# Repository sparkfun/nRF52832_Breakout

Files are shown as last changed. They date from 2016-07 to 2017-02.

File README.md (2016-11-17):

SparkFun nRF52832 Breakout
========================================

SparkFun nRF52832 Breakout (https://www.sparkfun.com/products/13990)

[*SparkFun nRF52832 Breakout (WRL-13990)*](https://www.sparkfun.com/products/13990)

The nRF52832 is [Nordic Semiconductor's](https://www.nordicsemi.com/eng/Products/Bluetooth-low-energy/nRF52832) latest multiprotocol radio system-on-chip (SoC). It's half microcontroller, with a list of features including 32 configurable I/O pins, SPI, I<sup>2</sup>C, UART, PWM, ADC's, 512kB flash, and 64kB RAM. And, it's half 2.4GHz multiprotocol radio, supporting **Bluetooth low energy** (BLE), **ANT**, and Nordic's proprietary 2.4GHz ultra low-power wireless communication -- it even features on-chip NFC tag support.

SparkFun's [nRF52832 Breakout](https://www.sparkfun.com/products/13990) provides easy access to all of the chip's features. It breaks out all of the nRF52's I/O pins, provides a 32.768kHz RTC crystal, a user-programmable button and LED, and a trace antenna to send and receive those 2.4GHz transmissions. Plus, to make the chip as easy-to-flash as possible, the breakout comes pre-programmed with a **serial bootloader**.

Repository Contents
-------------------

* **/Documentation** - Data sheets, additional product information
* **/Firmware** - Serial bootloader source and hex files
* **/Hardware** - Eagle design files (.brd, .sch)
* **/Production** - Production panel files (.brd)

Documentation
--------------
* **[Arduino Hardware Definitions](https://github.com/sparkfun/Arduino_Boards/)** - Arduino cores and tools for the nRF52.
* **[Hookup Guide](https://learn.sparkfun.com/tutorials/nrf52832-breakout-board-hookup-guide)** - Basic hookup guide for the nRF52832 Breakout.
* **[SparkFun Fritzing repo](https://github.com/sparkfun/Fritzing_Parts)** - Fritzing diagrams for SparkFun products.

Product Versions
----------------
* [SparkFun nRF52832 Breakout (WRL-13990)](https://www.sparkfun.com/products/13990)- Initial release of the nRF52832 Breakout

Version History
---------------

License Information
-------------------

This product is _**open source**_! 

Please review the LICENSE.md file for license information. 

If you have any questions or concerns on licensing, please contact techsupport@sparkfun.com.

Distributed as-is; no warranty is given.

- Your friends at SparkFun.

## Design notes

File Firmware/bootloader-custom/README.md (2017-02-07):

nRF52832 HCI/UART DFU Bootloader - From nRF5 SDK v11.0.0
======================================================

Device firmware update (DFU) bootloader which allows the nRF52832's firmware and/or SoftDevice to be updated serially.

[nrfutil v0.5.2](https://github.com/NordicSemiconductor/pc-nrfutil/releases/tag/v0.5.2) can be used to transfer a firmware image from computer to nRF52832.

To enter the bootloader, pin 6 -- attached to a button on the SparkFun nRF52832 Breakout -- must be held low on startup or reset. The LED on pin 7 will blink in a "timebomb" pattern to indicate the board is in the bootloader state.

For more information on the Nordic BLE & HCI/UART Bootloader/DFU, check out their [SDK Reference Page](http://infocenter.nordicsemi.com/topic/com.nordic.infocenter.sdk5.v11.0.0/examples_ble_dfu.html).

### Contents

* **/config** -- Platform-specific configurations.
* **/hex** -- Compiled hex files for the SoftDevice (S132) and bootloader.
* **main.c** -- Main source file for bootloader application

### Toolchain Requirements

To compile this bootloader, you'll need [armgcc](https://launchpad.net/gcc-arm-embedded) and Nordic's [nRF5_SDK_V11.0.0](https://developer.nordicsemi.com/nRF5_SDK/nRF5_SDK_v11.x.x/).

Documentation for the nRF5 SDK (v11.0.0) can be found at [http://infocenter.nordicsemi.com/index.jsp?topic=%2Fcom.nordic.infocenter.sdk5.v11.0.0%2Findex.html](http://infocenter.nordicsemi.com/index.jsp?topic=%2Fcom.nordic.infocenter.sdk5.v11.0.0%2Findex.html). Follow along with the instructions there to install and set up the SDK. Note that GCC is used instead of Keil or IAR.

### Building the Bootloader

Before building the bootloader, open the [Makefile](https://github.com/sparkfun/nRF52832_Breakout/blob/master/Firmware/bootloader-custom/Makefile) and modify `SDK_PATH` ([line 4](https://github.com/sparkfun/nRF52832_Breakout/blob/master/Firmware/bootloader-custom/Makefile#L4), setting the relative path to the **top-level path** of your Nordic SDK.

Once that is set, open this "bootloader-custom" folder in a command terminal and type `make`. `sfe_nrf52832_dfu.hex` should be created in a "_build" folder, which can be uploaded to the **Bootloader section** of the nRF52832's flash.

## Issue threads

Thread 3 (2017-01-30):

DFU Serial Instructions

boppana113, 2017-01-30:
Hi, I am using the Sparfun NRF52 breakout for a project and I want to develop my own PCB with it later. Is there any simple instruction guide on how to burn this specific bootloader program? Is there any specific hardware or software needed?

Thank you.

jimblom, 2017-02-07:
I've cleaned up the Makefile, and added a bit more to the [bootloader README](https://github.com/sparkfun/nRF52832_Breakout/blob/master/README.md), which documents how to build the bootloader.

To burn the bootloader onto an nRF52832, you'll need a hardware programmer. I'd recommend grabbing an [nRF52832 Development Kit](http://infocenter.nordicsemi.com/topic/com.nordic.infocenter.nrf52/dita/nrf52/development/nrf52_dev_kit.html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), which can serve as a development platform for the nRF52 as well as a programmer for external chips.

Software tools like [nRFgo Studio](https://www.nordicsemi.com/eng/Products/2.4GHz-RF/nRFgo-Studio/) or [Nordic's command-line tools](http://infocenter.nordicsemi.com/topic/com.nordic.infocenter.tools/dita/tools/nrf5x_command_line_tools/nrf5x_command_line_tools_lpage.html) can be used to load code onto the chip.

boppana113, 2017-03-31:
Hi Jimblom. I got the NRF52 DK and the Jlink EDU programmer. I was able to sucessfully program the sparkfun NRF52832 breakout board using Keil (J-link EDU). However, now I can't seem to go back and program through arduino. When I try to burn the bootloader using NRFgo studio and the bootloader hex file "sfe_nrf52832_dfu.hex" found in the repository it fails and gives an output saying:

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

Im not sure how to go around this. Thanks.

arihantdaga, 2018-08-03:
@boppana113 I am also stuck with this same thing for long time.. Did u find a solutions for this.. ?

Closed 2017-02-07.

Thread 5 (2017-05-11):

BOM C9 is missleading

PierreKircher, 2017-05-11:

santaimpersonator, 2019-12-30:
I know it has been a while and it might have been updated, but I just pulled the schematic (eagle file) and the values for C9 and C10 seem to match the labeling at 6pF.

Are you possibly referring to C13 and C14, which are at 15pF?

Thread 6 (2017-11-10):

Flashing the bootloader

chaitzatkano, 2017-11-10:
Hi,

Can you please confirm the command to flash the bootloader to sparkfun nrf52 breakout board?
I am trying to generate a zip of bootloader and softdevice using the following command but nrfutil throws error.

The command is
nrfutil dfu genpkg bootloader.zip --bootloader sfe_nrf52832_dfu.hex --softdevice s132_nrf52_2.0.0_softdevice.hex  --dev-type 52 --sd-req 0x81

EliKrumholz, 2018-03-27:
Commenting in case it helps someone else. I needed to re-flash the bootloader on an nRF52 breakout board, I had to use a J-Link over the SWD connector, the nRF52 dev kit with onboard J-Link can be used: https://www.nordicsemi.com/eng/Products/Bluetooth-low-energy/nRF52-DK, but I used the J-Link Base. I needed to merge the provided hex files into a single hex file and then program the board using nrfjprog:

```
mergehex -m s132_nrf52_2.0.0_softdevice.hex sfe_nrf52832_dfu.hex -o merged.hex // Merge hex files
nrfjprog -e // Erase nRF52
nrfjprog -r --program merged.hex // Program the breakout board and reset
```

Afterwards the device entered bootloader mode as indicated by the blue LED blinking in the "timebomb" pattern and I was able to program the device over serial with an FTDI breakout board.

mhaberler, 2020-06-05:
MacOS Catalina user here - some more data points:

Acquired a [Black Magic Probe](https://1bitsquared.com/products/black-magic-probe) for gdb debugging

Managed to wipe the DFU bootloader with gdb 'monitor erase_mass' and figured I'll have to reflash it like [hinted here](https://learn.sparkfun.com/tutorials/nrf52832-breakout-board-hookup-guide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)

rebuilt bootloader from this repo as per [README](https://github.com/sparkfun/nRF52832_Breakout/tree/master/Firmware/bootloader-custom) using the [9-2020-q2-update armgcc](https://developer.arm.com/tools-and-software/open-source-software/developer-tools/gnu-toolchain/gnu-rm/downloads) - the MacOS package installs in /Applications/ARM so Makefile.posix needs adjusting for this location

eventually figured out this build was not necessary in the first place since the [hex files](https://github.com/sparkfun/nRF52832_Breakout/tree/master/Firmware/bootloader-custom/hex) are just fine
merged those hex files as described above:
````
mergehex -m s132_nrf52_2.0.0_softdevice.hex sfe_nrf52832_dfu.hex -o merged.hex

````
attached the BMP SWD wires and supplied power from the serial black and red wires to GND and VIN (probably pin 3V3 works as well as power from the BMP is 3.3V)

loaded the bootloader like so:

````
$ /Applications/ARM/bin/arm-none-eabi-gdb
target extended-remote /dev/cu.usbmodemC1DDB5BD1
# turns on power on the serial VCC wire
monitor tpwr enable
# check what's out there
monitor swdp_scan
att 1
# wipe everyting
monitor erase_mass
# load the merged bootloader
file <path to>/merged.hex
# flash it
load
# verify this worked
compare-sections
# disconnect
kill
# confirm disconnect
# blue LED should show 'timebomb pattern'
````

I assumed I would be able to serially program the board with the BMP serial port - for reasons which I do not understand this does not work

however, connecting a normal FTDI USB serial converter to GND/TX/RX and powering the board as before from the BMP does work, also from Arduino

I did have issues with the FTDI adapter as well until I installed the [2.4.4 FTDI MacOS driver](http://www.ftdicommunity.com/index.php?topic=505.0) - all the 'FTDI serial dongles do not reappear after disconnect/reconnect' issues are gone

still interested in getting the BMP serial port to work but at least back to a working config

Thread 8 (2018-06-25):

Compiling the Bootloader

roobituk, 2018-06-25:
I can't seem to `make` the boot-loader custom on Windows 10.

I've download the `arm-none-eabi-gcc` toolchain and I've installed GnuMake yet when I run make inside the `bootloader-custom` directory, I get the following errors:

```
rm -rf _build
process_begin: CreateProcess(NULL, rm -rf _build, ...) failed.
make (e=2): The system cannot find the file specified.
make: *** [clean] Error 2
```

Any advice would be greatly appreciated!

roobituk, 2018-06-25:
Ok, so installing `CoreUtils` for Windows solved the problem.

Closed 2018-06-25.

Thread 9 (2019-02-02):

ADC internal reference

Benni77, 2019-02-02:
Hey guys,
the internal reference of my Sparkfun Break out seams to be 0.6V on the Analog input. I need to change the gain setting to round about 3.3V. Is there any chance?
I found something for the adafruit board (analogReference(...)) but it's not working on the Sparkfun Break out.
Is there any chance?

Cheers :)

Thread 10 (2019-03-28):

Compiling bootloader from scratch

TamojitSaha, 2019-03-28:
I followed the exact steps mention to compile the bootloader. I also installed **GnuMake**.
I am using **8 2018-q4-major** version as _ARM GCC ToolChain_.  Platform: _Windows 10_
_PATH_ variables are also added and can be accessed by CMD.

Whenever I run `make sfe_nrf52832_dfu`, I get the following error:
```
E:\Projects\nRF52832_Breakout\Firmware\bootloader-custom>make sfe_nrf52832_dfu
Compiling file: app_error.c
process_begin: CreateProcess(NULL, "C:/Program Files (x86)/GNU Tools ARM Embedded/4.9 2015q1/bin/arm-none-eabi-gcc" -DNRF52 -DBOARD_CUSTOM -DNRF52_PAN_12 -DNRF52_PAN_15 -DNRF52_PAN_58 -DNRF52_PAN_55 -DNRF52_PAN_54 -DNRF52_PAN_31 -DNRF52_PAN_30 -DNRF52_PAN_51 -DNRF52_PAN_36 -DNRF52_PAN_53 -D__HEAP_SIZE=0 -DS132 -DCONFIG_GPIO_AS_PINRESET -DBLE_STACK_SUPPORT_REQD -DBSP_DEFINES_ONLY -DSWI_DISABLE0 -DNRF52_PAN_20 -DNRF52_PAN_64 -DSOFTDEVICE_PRESENT -DNRF52_PAN_62 -DNRF52_PAN_63 -mcpu=cortex-m4 -mthumb -mabi=aapcs --std=gnu99 -Wall -Werror -Os -g3 -mfloat-abi=hard -mfpu=fpv4-sp-d16 -ffunction-sections -fdata-sections -fno-strict-aliasing -fno-builtin --short-enums -I ./config/dfu_dual_bank_serial_s132_pca10040 -I ./config -I E:/Projects/Nrf52832_SDK/nRF5_SDK_11.0.0_89a8197/components/libraries/bootloader_dfu/hci_transport -I E:/Projects/Nrf52832_SDK/nRF5_SDK_11.0.0_89a8197/components/libraries/bootloader_dfu -I E:/Projects/Nrf52832_SDK/nRF5_SDK_11.0.0_89a8197/components/libraries/scheduler -I E:/Projects/Nrf52832_SDK/nRF5_SDK_11.0.0_89a8197/components/drivers_nrf/config -I E:/Projects/Nrf52832_SDK/nRF5_SDK_11.0.0_89a8197/examples/bsp -I E:/Projects/Nrf52832_SDK/nRF5_SDK_11.0.0_89a8197/components/drivers_nrf/delay -I E:/Projects/Nrf52832_SDK/nRF5_SDK_11.0.0_89a8197/components/libraries/crc16 -I E:/Projects/Nrf52832_SDK/nRF5_SDK_11.0.0_89a8197/components/softdevice/s132/headers/nrf52 -I E:/Projects/Nrf52832_SDK/nRF5_SDK_11.0.0_89a8197/components/libraries/util -I E:/Projects/Nrf52832_SDK/nRF5_SDK_11.0.0_89a8197/components/drivers_nrf/pstorage -I E:/Projects/Nrf52832_SDK/nRF5_SDK_11.0.0_89a8197/components/drivers_nrf/uart -I E:/Projects/Nrf52832_SDK/nRF5_SDK_11.0.0_89a8197/components/ble/common -I E:/Projects/Nrf52832_SDK/nRF5_SDK_11.0.0_89a8197/components/libraries/hci/config -I E:/Projects/Nrf52832_SDK/nRF5_SDK_11.0.0_89a8197/components/libraries/uart -I E:/Projects/Nrf52832_SDK/nRF5_SDK_11.0.0_89a8197/components/device -I E:/Projects/Nrf52832_SDK/nRF5_SDK_11.0.0_89a8197/components/libraries/hci -I E:/Projects/Nrf52832_SDK/nRF5_SDK_11.0.0_89a8197/components/libraries/timer -I E:/Projects/Nrf52832_SDK/nRF5_SDK_11.0.0_89a8197/components/softdevice/s132/headers -I E:/Projects/Nrf52832_SDK/nRF5_SDK_11.0.0_89a8197/components/toolchain/CMSIS/Include -I E:/Projects/Nrf52832_SDK/nRF5_SDK_11.0.0_89a8197/components/drivers_nrf/hal -I E:/Projects/Nrf52832_SDK/nRF5_SDK_11.0.0_89a8197/components/toolchain/gcc -I E:/Projects/Nrf52832_SDK/nRF5_SDK_11.0.0_89a8197/components/toolchain -I E:/Projects/Nrf52832_SDK/nRF5_SDK_11.0.0_89a8197/components/drivers_nrf/common -I E:/Projects/Nrf52832_SDK/nRF5_SDK_11.0.0_89a8197/components/softdevice/common/softdevice_handler -I E:/Projects/Nrf52832_SDK/nRF5_SDK_11.0.0_89a8197/components/libraries/simple_timer -I E:/Projects/Nrf52832_SDK/nRF5_SDK_11.0.0_89a8197/components/drivers_nrf/timer -c -o _build/app_error.o E:/Projects/Nrf52832_SDK/nRF5_SDK_11.0.0_89a8197/components/libraries/util/app_error.c, ...) failed.
make (e=2): The system cannot find the file specified.
make: *** [_build/app_error.o] Error 2
```
I also do not understand how `4.9 2015q1` version is taken while compiling. I have a different version installed and added to _PATH_

Please help me debug the problem.
If there is anything more information to be provided, I will be glad to do so.

beegee-tokyo, 2019-05-16:
You need to edit the Makefile and change the lines 39 and 40 to match the path to your GNU tools.

For me they look like:
```
PROGFILES = B:/DevTools
GNU_INSTALL_ROOT = $(PROGFILES)/GNU Tools ARM Embedded/8 2018-q4-major
```

But even with that make failed for me while linking with
```
Linking target: feather52832_bootloader.out
Preparing: feather52832_bootloader.hex feather52832_bootloader_6.0.0_s132.hex
B:\DevTools\GNU Tools ARM Embedded\8 2018-q4-major\bin\arm-none-eabi-objcopy.exe: _build/feather52832_bootloader.hex 64-bit address 0x4b4fa300074000 out of range for Intel Hex file
B:\DevTools\GNU Tools ARM Embedded\8 2018-q4-major\bin\arm-none-eabi-objcopy.exe:_build/feather52832_bootloader.hex: bad value
make[2]: *** [Makefile:319: genhex] Error 1
make[1]: *** [Makefile:284: feather52832] Error 2
make: *** [Makefile:247: all] Error 2
```

Still trying to figure out why.

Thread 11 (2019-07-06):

Flashing bootloader into nrf52832

kungfupizza, 2019-07-06:
Hi,
I have a STM32 based JTAG connector with SWD connectivity. I have connected this to the nrf52832 board but having these errors with nrfutil
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

Please help.

jpconstantineau, 2019-07-06:
nrfutil is being called for flashing with serial, not swd.

On Sat, 6 Jul 2019 at 05:09, Sarthak Kelapure <notifications@github.com>
wrote:

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

--
Pierre

kungfupizza, 2019-07-06:
I also tried flashing the bootloader using P26 and P27 connected via a FTDI but that doesn't do anything. What is the exact procedure? Any post to help me flash bootloader into blank new nrf52832?

Closed 2019-07-09.

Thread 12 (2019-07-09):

Programming custom nrf52832 board

kungfupizza, 2019-07-09:
Hi,
I was using Sparkfun nRF52832 board to test my application, programming it with FTDI over Arduino IDE. Now I made my own PCB and found out that the IC doesn't have bootloader in it and I cannot program it using Arduino IDE.

Fortunately I have SWDIO, SWCLK, P26 and P27 pins available for me out along with a RST and P06 button.

For HW, I have ST-Link v2 and some STM32 boards with SWD. I have also bought a nrf52 DK.

How do I start with this blank IC now? Any solution?

santaimpersonator, 2019-12-30:
Unfortunately, this isn't actually an issue with the board and is more of a technical assistance related question. Please head of to our [forum](https://forum.sparkfun.com/) and post a topic. Please note that your issue is probably outside the scope of our support team and may not be address by them directly (i.e. they may just point you to some useful resources). However, someone in the community may be able to help.

That being said, it looks like we cover how to program the bootloader in the [hookup guide](https://learn.sparkfun.com/tutorials/nrf52832-breakout-board-hookup-guide#resources--going-further).

Closed 2019-12-30.

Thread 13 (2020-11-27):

Antenna layout

FranzImsch, 2020-11-27:
I think the ground connection of the impedance matching capacitor closest to the nRF should the other way around. According to Nordic, the cap's ground should be connected only to the chip's pin and not to the ground plane. This is how they did it in their reference design as well. Or am I missing something?

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

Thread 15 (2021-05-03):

Analog input readings

TurnerRussell50, 2021-05-03:
Customer states via forums:
**It appears that there is a setting for reading analog voltages missing or needs to be added.

Trying to read 0 to 3 volts on an analog input pin. Anything over a few hundred mV over ranges the readings. I've seen code that attempts to fix this but I can't get it to work.

The added line I have seen is:

analogReference(AR_VDD4);**

https://forum.sparkfun.com/viewtopic.php?f=182&t=55650&p=225574#p225574

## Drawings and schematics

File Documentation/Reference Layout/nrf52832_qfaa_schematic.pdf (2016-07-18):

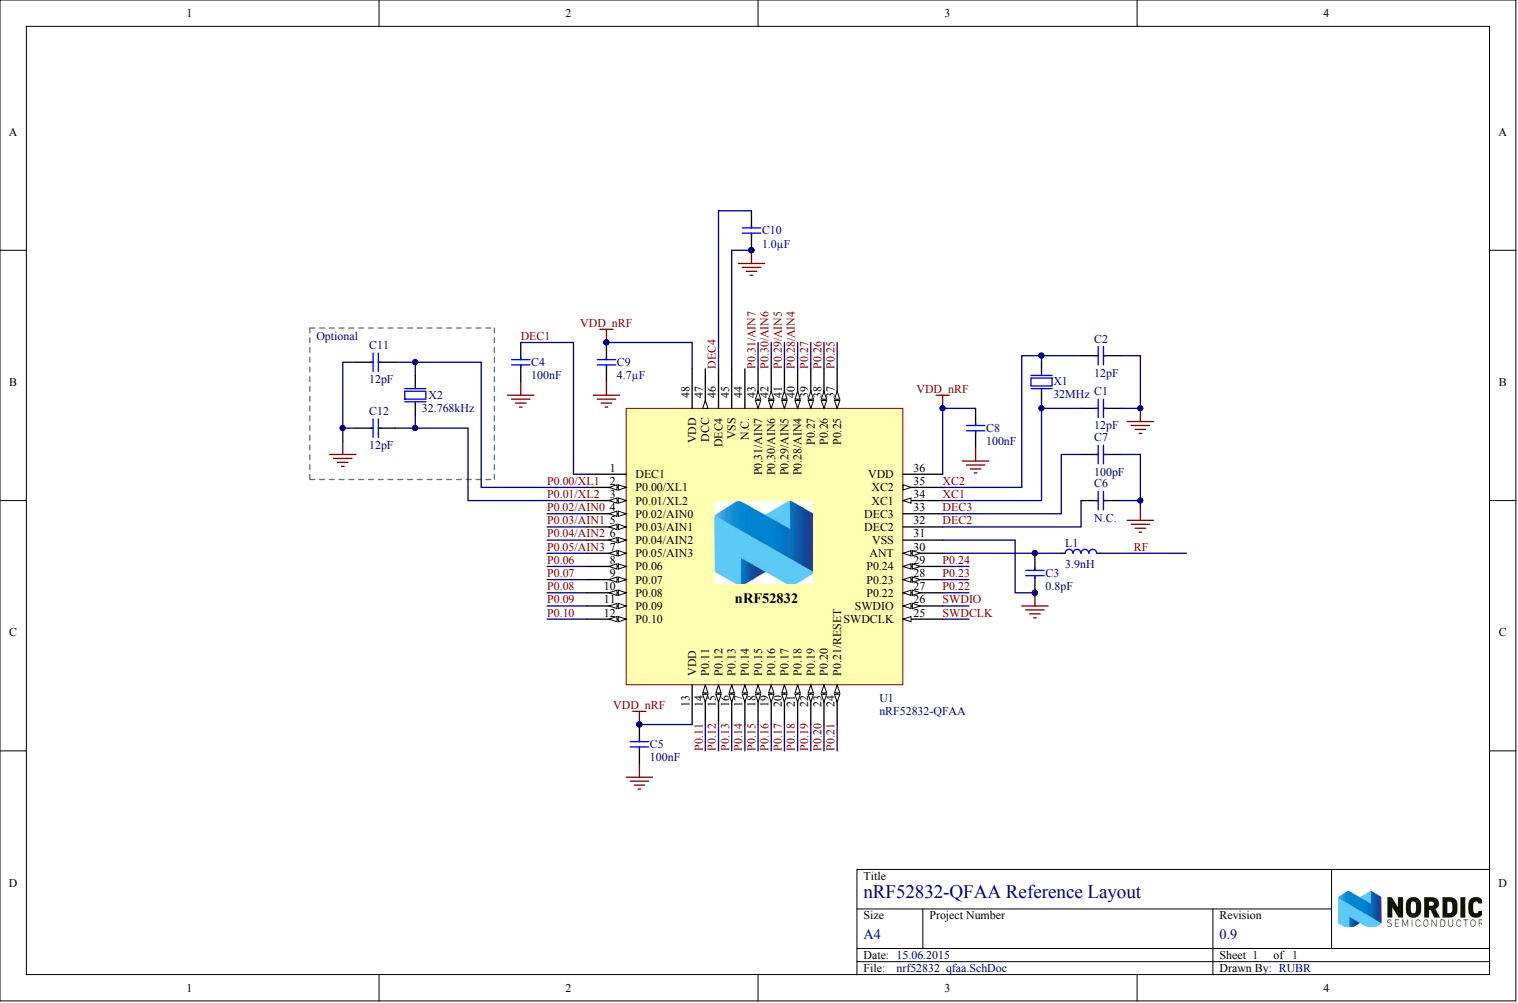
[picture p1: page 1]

Title nRF52832-QFAA Reference Layout

Size A4 | Project Number | Revision 0.9

Date: 15.06.2015 | Sheet 1 of 1
File: nrf52832_qfaa.SchDoc | Drawn By: RUBR

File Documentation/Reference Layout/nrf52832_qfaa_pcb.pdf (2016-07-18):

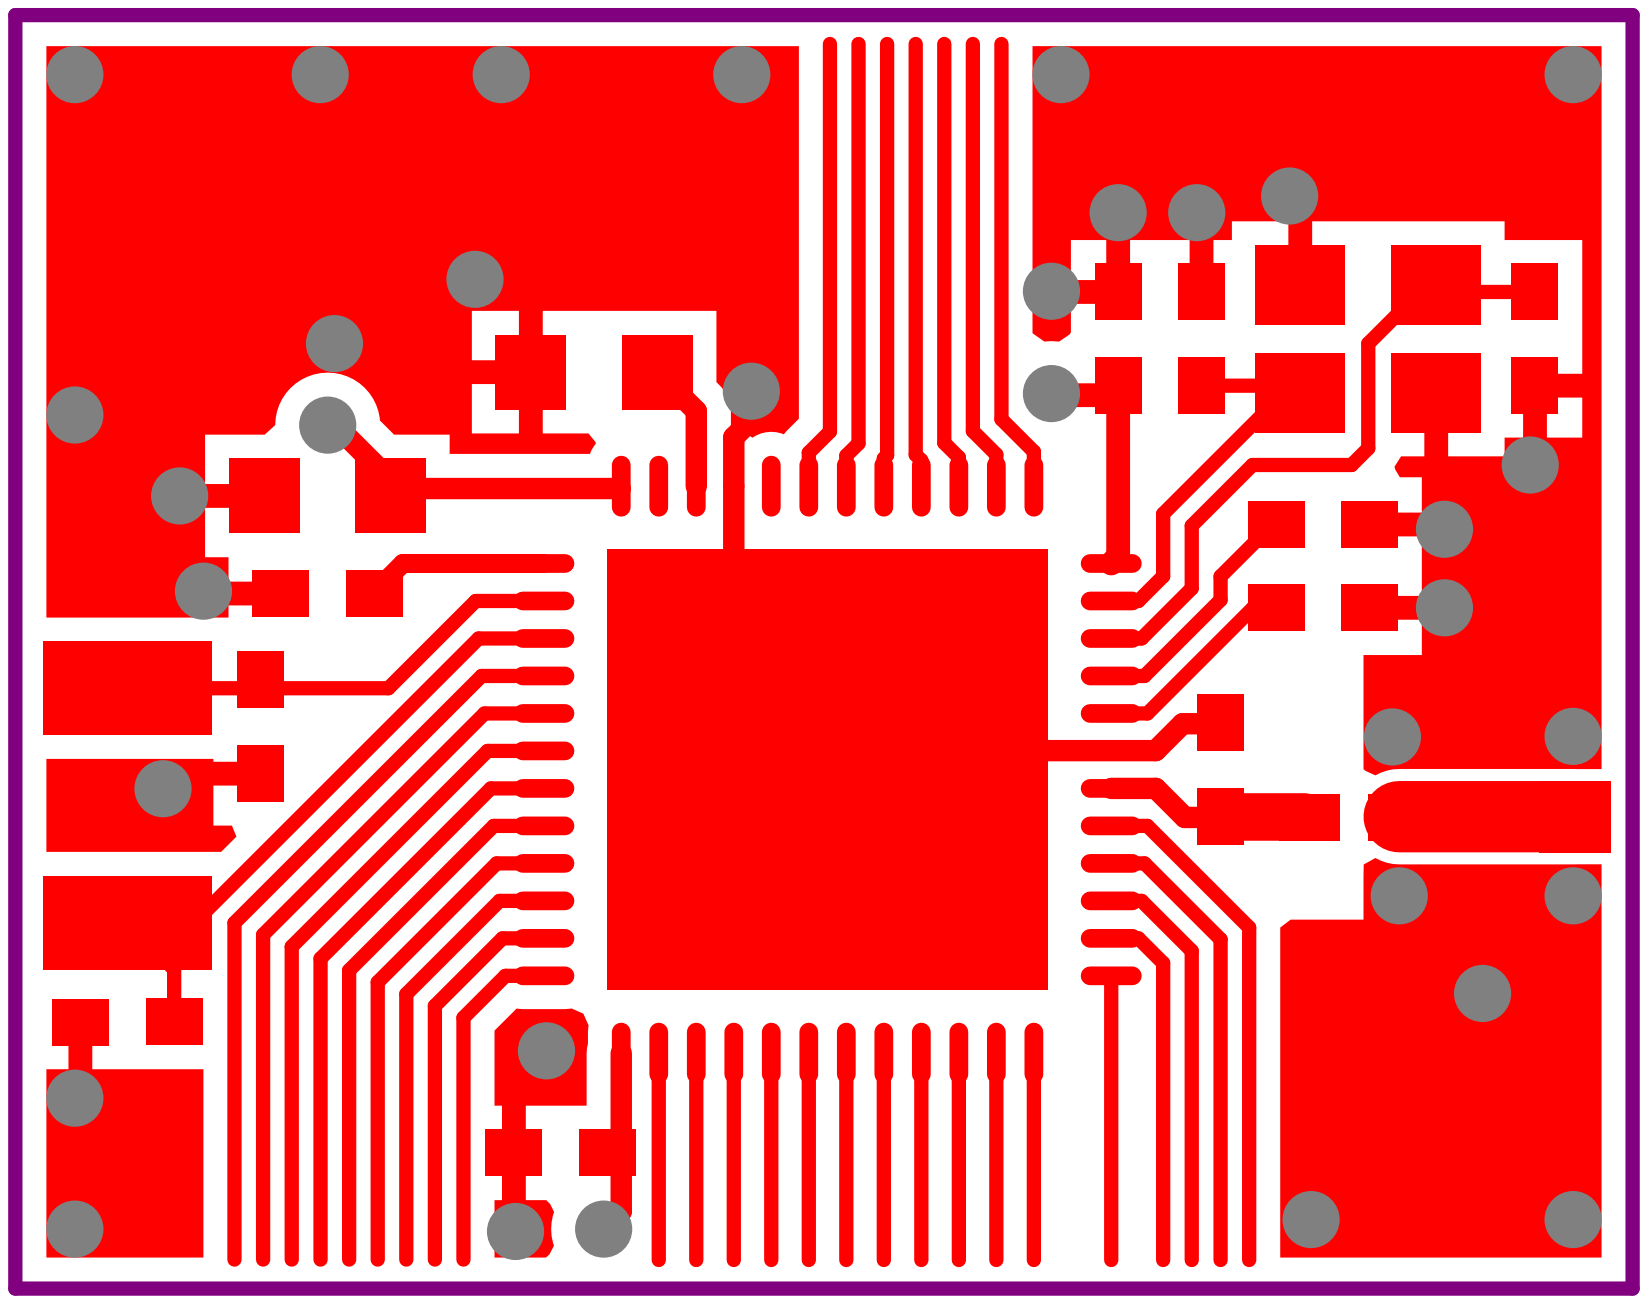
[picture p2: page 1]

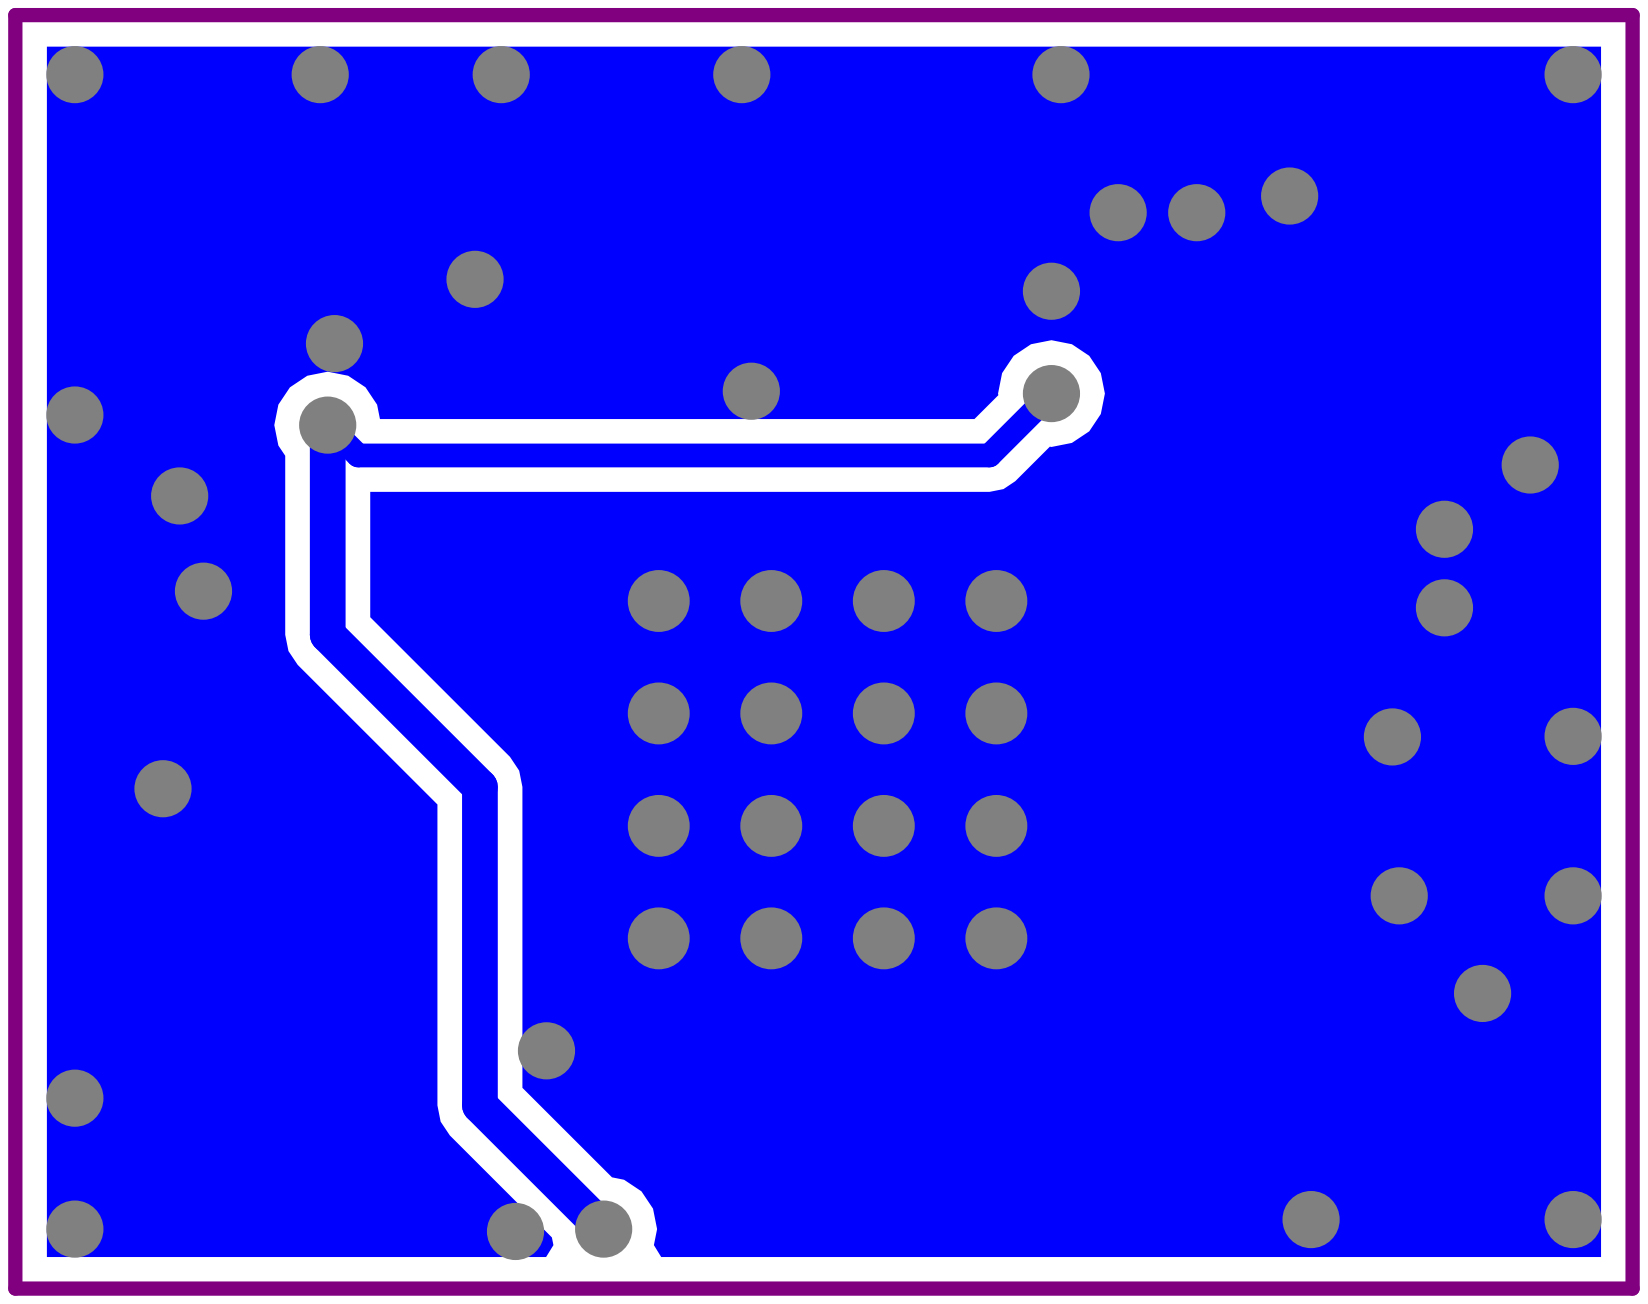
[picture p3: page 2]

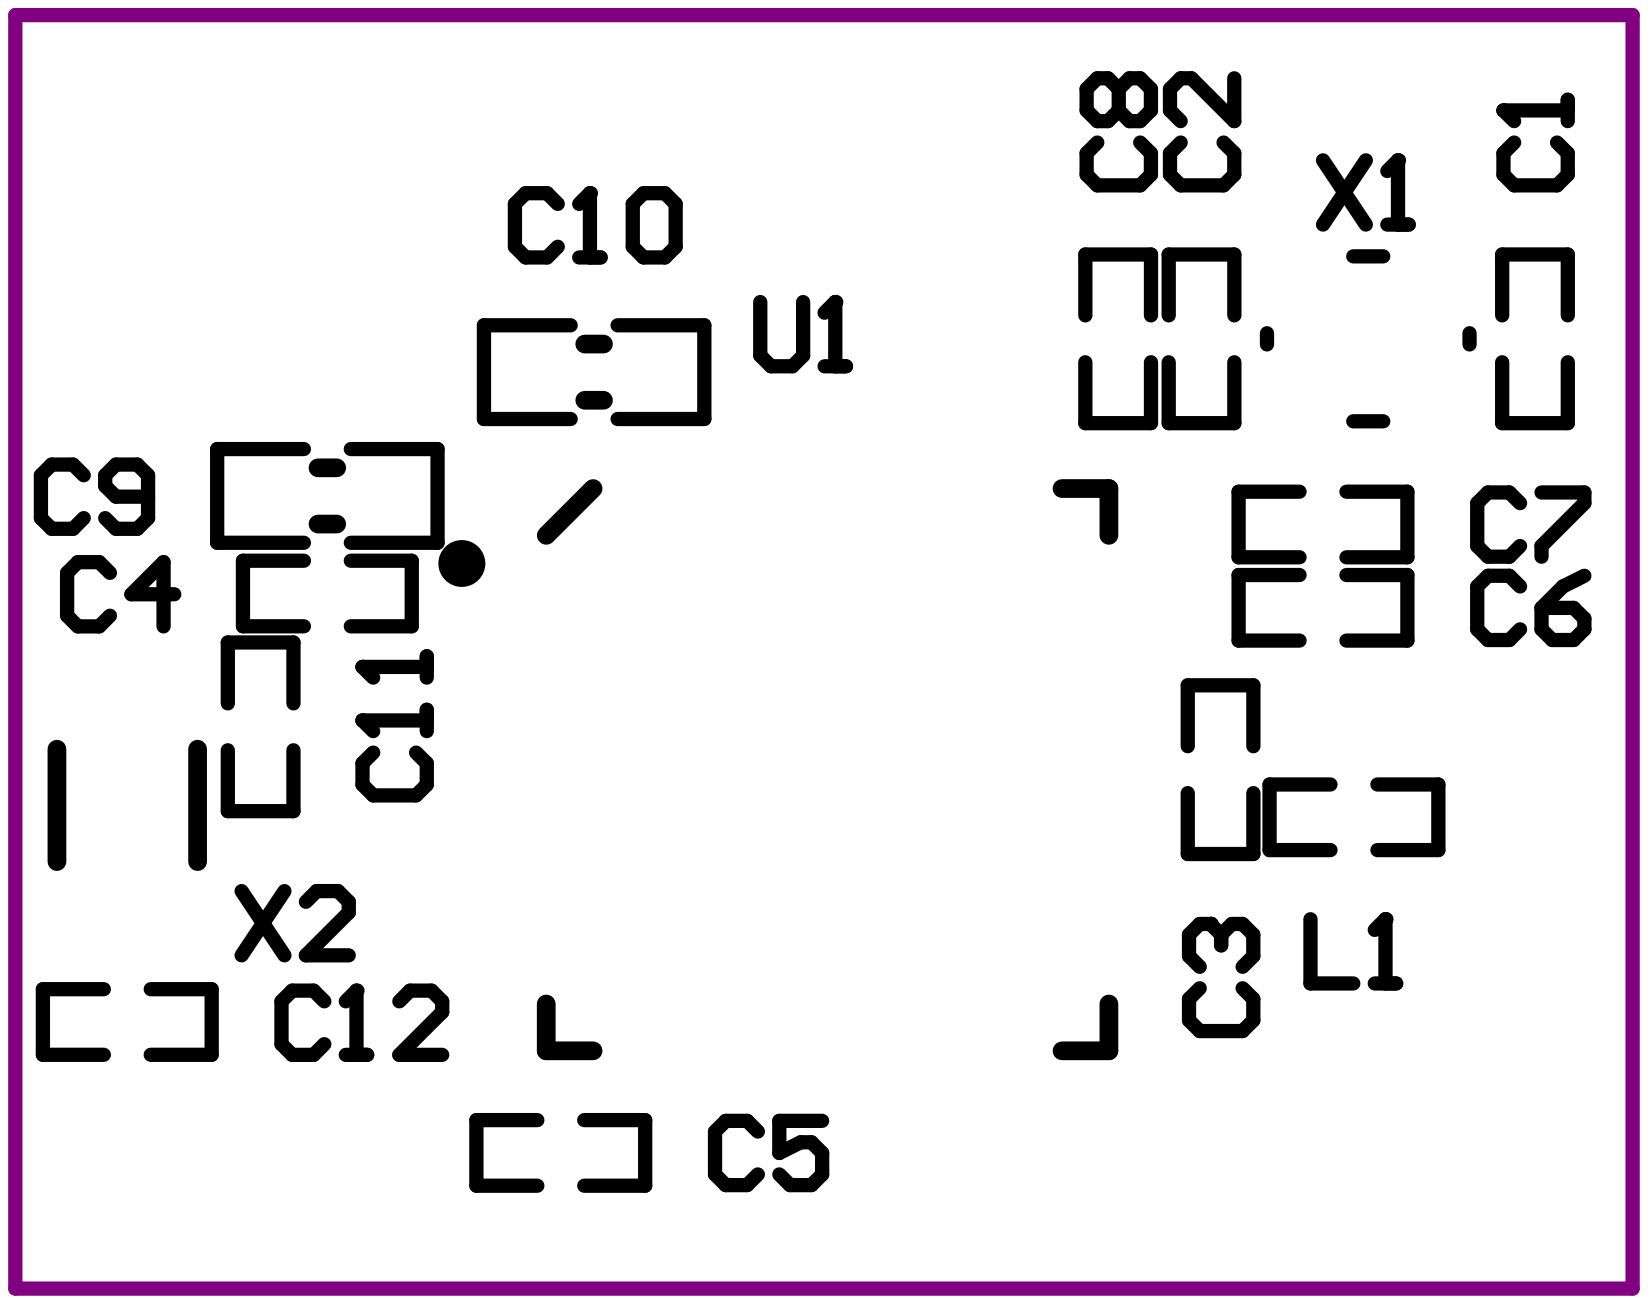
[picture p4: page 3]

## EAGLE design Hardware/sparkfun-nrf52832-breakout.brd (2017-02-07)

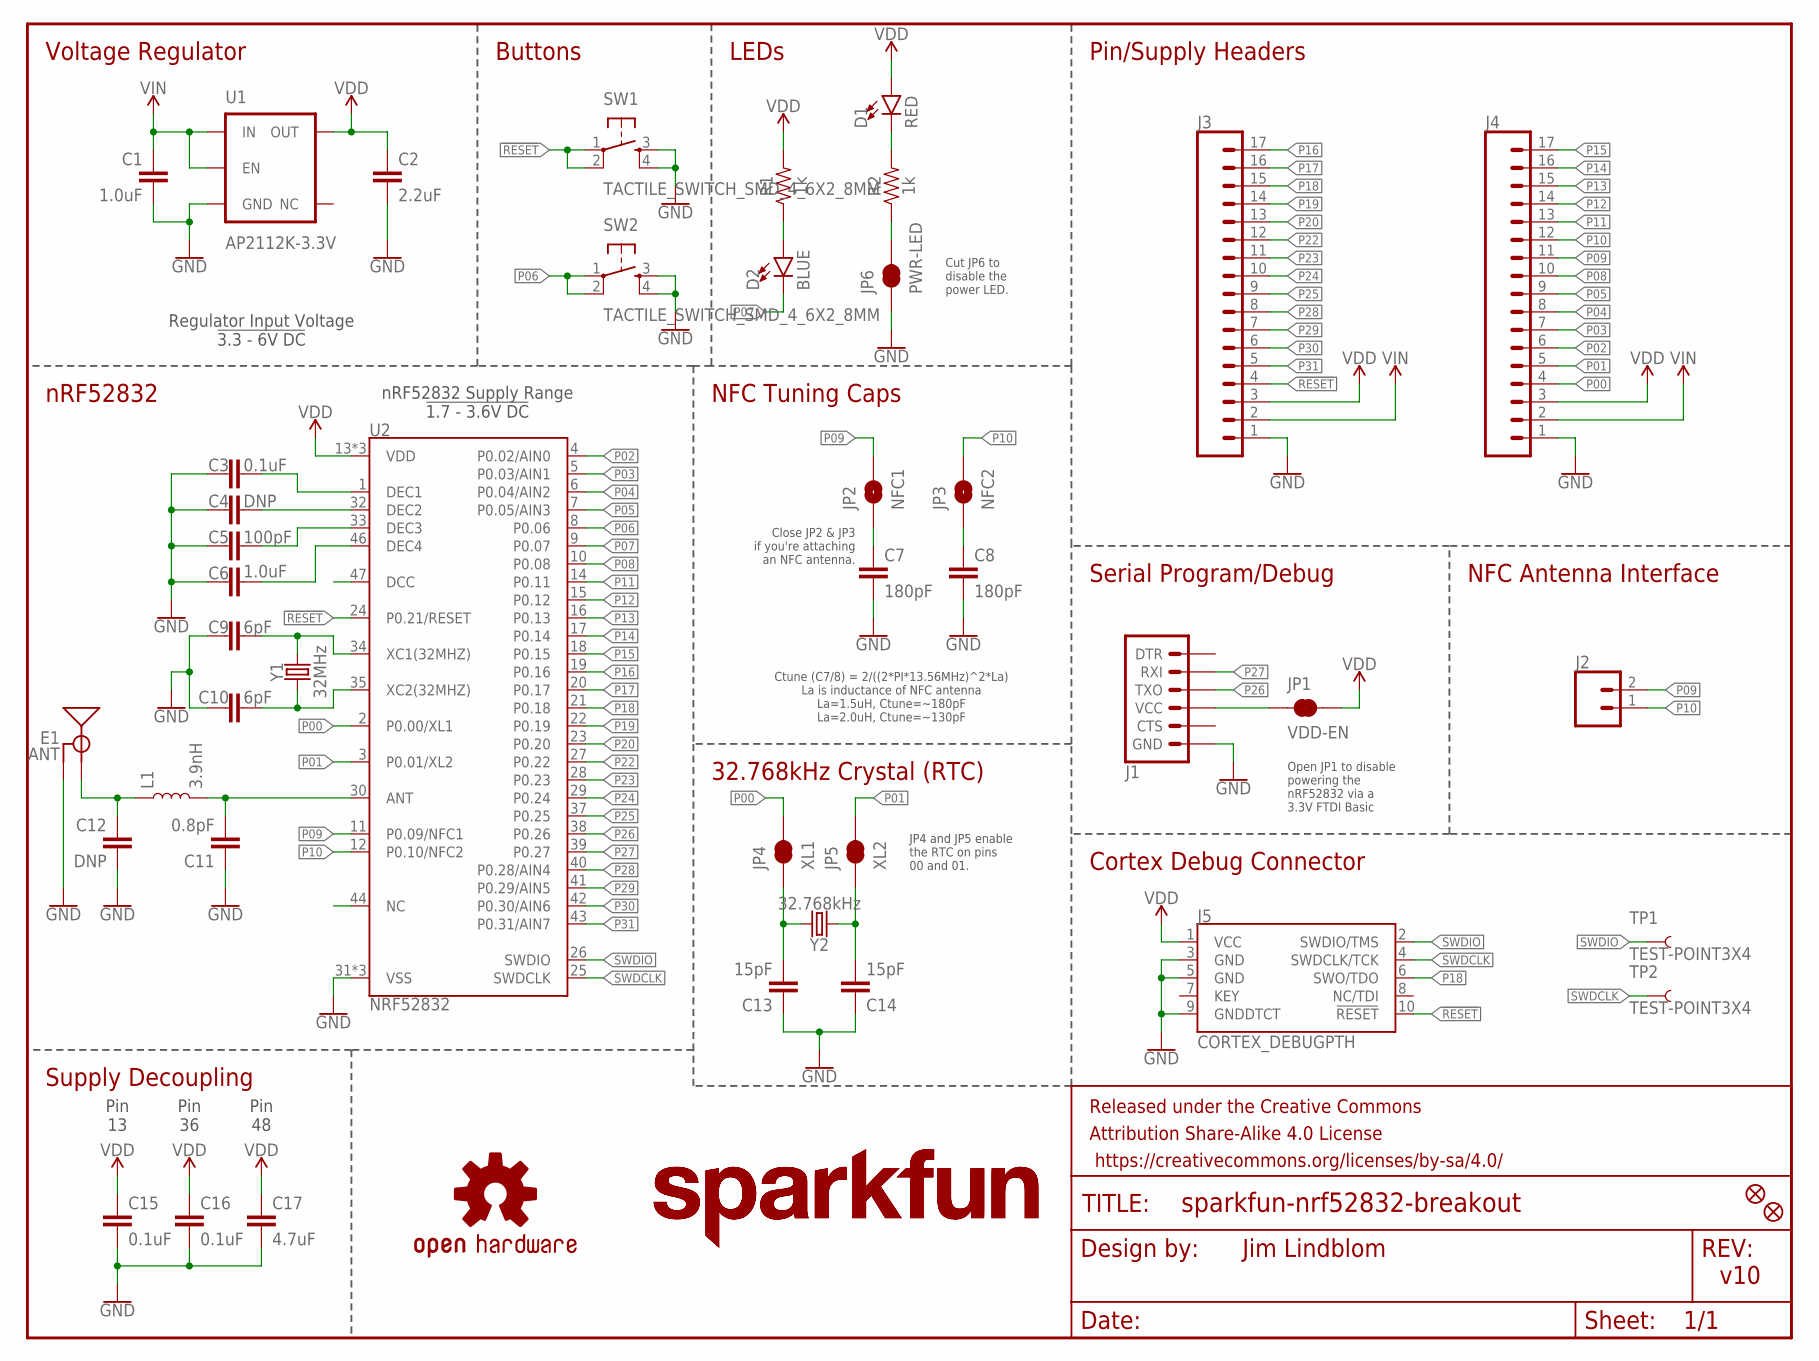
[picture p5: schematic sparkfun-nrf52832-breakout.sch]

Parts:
C1: 1.0uF; 0603
C2: 2.2uF; 0603
C3, C15, C16: 0.1uF; 0402
C4, C12: DNP; 0402
C5: 100pF; 0402
C6: 1.0uF; 0402
C7, C8: 180pF; 0603
C9, C10: 6pF; 0402
C11: 0.8pF; 0402
C13, C14: 15pF; 0402
C17: 4.7uF; 0603
D1: RED; LED-0603
D2: BLUE; LED-0603
E1: ANT; TRACE_ANTENNA_2.4GHZ_15.2MM
FD1, FD2: FIDUCIALUFIDUCIAL; FIDUCIAL-MICRO
FRAME1: FRAME-LETTER; CREATIVE_COMMONS
J1: ARDUINO_SERIAL_PROGRAMPTH; 1X06
J2: CONN_02PTH; 1X02
J3, J4: CONN_17; 1X17
J5: CORTEX_DEBUGPTH; 2X5-PTH-1.27MM
JP1: VDD-EN; SMT-JUMPER_2_NC_TRACE_SILK
JP2: NFC1; SMT-JUMPER_2_NO_SILK
JP3: NFC2; SMT-JUMPER_2_NO_SILK
JP4: XL1; PAD-JUMPER-2-NC_BY_TRACE_YES_SILK
JP5: XL2; PAD-JUMPER-2-NC_BY_TRACE_YES_SILK
JP6: PWR-LED; PAD-JUMPER-2-NC_BY_TRACE_YES_SILK
L1: 3.9nH; 0402
LOGO1: OSHW-LOGOMINI; OSHW-LOGO-MINI
LOGO2, LOGO3: SFE_LOGO_NAME.1_INCH; SFE_LOGO_NAME_.1
R1, R2: 1k; 0603
SW1, SW2: TACTILE_SWITCH_SMD_4_6X2_8MM; TACTILE_SWITCH_SMD_4.6X2.8MM
TP1, TP2: TEST-POINT3X4; PAD.03X.04
U1: AP2112K-3.3V; SOT23-5
U2: NRF52832; QFN48-6X6MM
Y1: 32MHz; CRYSTAL-SMD-2.0X1.6MM
Y2: 32.768kHz; CRYSTAL-SMD-3.2X1.5MM

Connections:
!RESET!: J3.4, J5.10 (!RESET), SW1.1, SW1.2, U2.24 (P0.21/RESET)
ANT: C11.2, L1.2, U2.30 (ANT)
DCC: U2.47 (DCC)
DEC1: C3.2, U2.1 (DEC1)
DEC2: C4.2, U2.32 (DEC2)
DEC3: C5.2, U2.33 (DEC3)
DEC4: C6.2, U2.46 (DEC4)
GND: C1.2, C2.2, C3.1, C4.1, C5.1, C6.1, C7.2, C8.2, C9.1, C10.2, C11.1, C12.2, C13.1, C14.1, C15.2, C16.2, C17.2, E1.GND, J1.6 (GND), J3.1, J4.1, J5.3 (GND), J5.5 (GND), J5.9 (GNDDTCT), JP6.1, SW1.3, SW1.4, SW2.3, SW2.4, U1.2 (GND), U2.31 (VSS), U2.45 (VSS), U2.EP (VSS)
unnamed: JP6.2, R2.1
unnamed: C13.2, JP4.1, Y2.P$2 (2)
unnamed: C14.2, JP5.1, Y2.P$1 (1)
unnamed: C12.1, E1.ANT (SIGNAL), L1.1
unnamed: D1.C, R2.2
unnamed: J1.4 (VCC), JP1.1
unnamed: D2.A, R1.1
NC: U2.44 (NC)
NFC1: C7.1, JP2.1
NFC2: C8.1, JP3.1
P00: J4.4, JP4.2, U2.2 (P0.00/XL1)
P01: J4.5, JP5.2, U2.3 (P0.01/XL2)
P02: J4.6, U2.4 (P0.02/AIN0)
P03: J4.7, U2.5 (P0.03/AIN1)
P04: J4.8, U2.6 (P0.04/AIN2)
P05: J4.9, U2.7 (P0.05/AIN3)
P06: SW2.1, SW2.2, U2.8 (P0.06)
P07: D2.C, U2.9 (P0.07)
P08: J4.10, U2.10 (P0.08)
P09: J2.2, J4.11, JP2.2, U2.11 (P0.09/NFC1)
P10: J2.1, J4.12, JP3.2, U2.12 (P0.10/NFC2)
P11: J4.13, U2.14 (P0.11)
P12: J4.14, U2.15 (P0.12)
P13: J4.15, U2.16 (P0.13)
P14: J4.16, U2.17 (P0.14)
P15: J4.17, U2.18 (P0.15)
P16: J3.17, U2.19 (P0.16)
P17: J3.16, U2.20 (P0.17)
P18: J3.15, J5.6 (SWO/TDO), U2.21 (P0.18)
P19: J3.14, U2.22 (P0.19)
P20: J3.13, U2.23 (P0.20)
P22: J3.12, U2.27 (P0.22)
P23: J3.11, U2.28 (P0.23)
P24: J3.10, U2.29 (P0.24)
P25: J3.9, U2.37 (P0.25)
P26: J1.3 (TXO), U2.38 (P0.26)
P27: J1.2 (RXI), U2.39 (P0.27)
P28: J3.8, U2.40 (P0.28/AIN4)
P29: J3.7, U2.41 (P0.29/AIN5)
P30: J3.6, U2.42 (P0.30/AIN6)
P31: J3.5, U2.43 (P0.31/AIN7)
SWDCLK: J5.4 (SWDCLK/TCK), TP2.P$1, U2.25 (SWDCLK)
SWDIO: J5.2 (SWDIO/TMS), TP1.P$1, U2.26 (SWDIO)
VDD: C2.1, C15.1, C16.1, C17.1, D1.A, J3.3, J4.3, J5.1 (VCC), JP1.2, R1.2, U1.5 (OUT), U2.13 (VDD), U2.36 (VDD), U2.48 (VDD)
VIN: C1.1, J3.2, J4.2, U1.1 (IN), U1.3 (EN)
XC1: C9.2, U2.34 (XC1(32MHZ)), Y1.3 (2)
XC2: C10.1, U2.35 (XC2(32MHZ)), Y1.1

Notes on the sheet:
Pin 13
Pin 36
Pin 48
v10
Jim Lindblom
Ctune (C7/8) = 2/((2*PI*13.56MHz)^2*La) La is inductance of NFC antenna La=1.5uH, Ctune=~180pF La=2.0uH, Ctune=~130pF
Voltage Regulator
Buttons
LEDs
Pin/Supply Headers
nRF52832
32.768kHz Crystal (RTC)
Supply Decoupling
NFC Tuning Caps
Cortex Debug Connector
Serial Program/Debug
NFC Antenna Interface
Open JP1 to disable powering the nRF52832 via a 3.3V FTDI Basic
Close JP2 & JP3 if you're attaching an NFC antenna.
JP4 and JP5 enable the RTC on pins 00 and 01.
Regulator Input Voltage !3.3 - 6V DC!
nRF52832 Supply Range !1.7 - 3.6V DC!
Cut JP6 to disable the power LED.

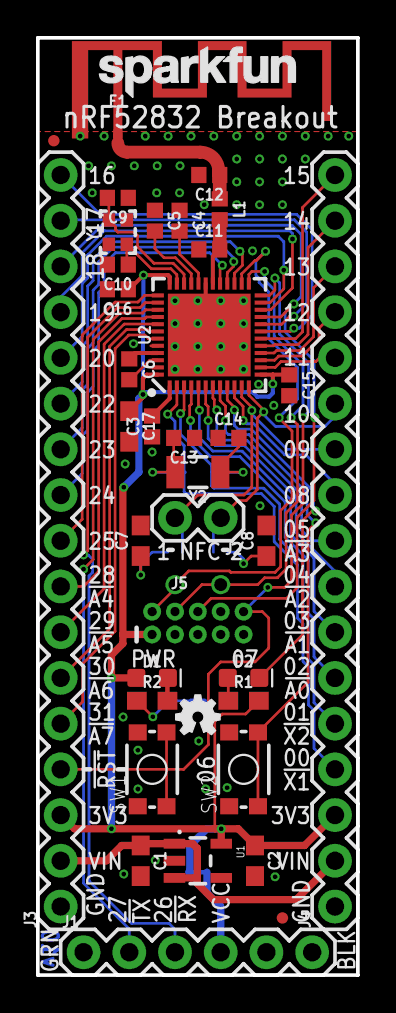
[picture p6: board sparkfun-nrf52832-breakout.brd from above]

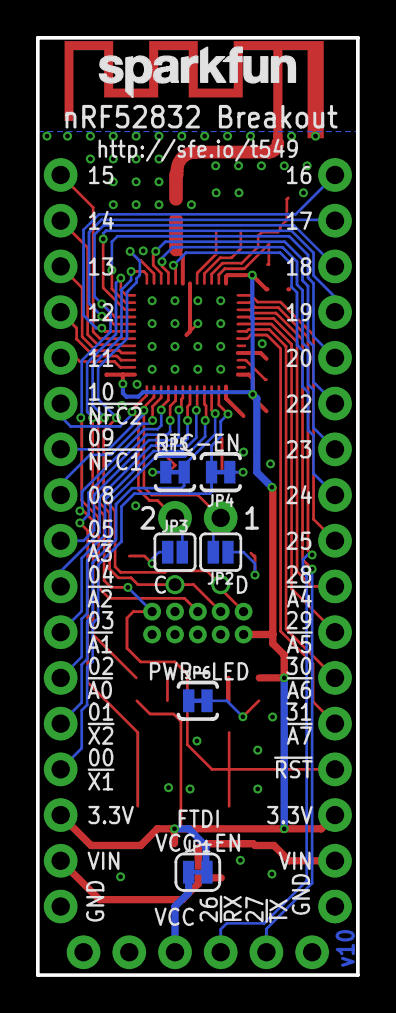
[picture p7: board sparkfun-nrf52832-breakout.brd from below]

Board: 2 copper layers, 17.8 x 52.1 mm, 48 parts (9 on the bottom side), 53 nets.

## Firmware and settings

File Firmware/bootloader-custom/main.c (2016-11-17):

/* nRF52832 HCI/UART DFU Bootloader - From nRF5 SDK v11.0.0
 * Copyright (c) 2013 Nordic Semiconductor. All Rights Reserved.
 *
 * The information contained herein is property of Nordic Semiconductor ASA.
 * Terms and conditions of usage are described in detail in NORDIC
 * SEMICONDUCTOR STANDARD SOFTWARE LICENSE AGREEMENT.
 *
 * Licensees are granted free, non-transferable use of the information. NO
 * WARRANTY of ANY KIND is provided. This heading must NOT be removed from
 * the file.
 *
 * Modified by: SparkFun Electronics
 * LED blink indicator added and new board definition for the SparkFun
 * nRF52832 Breakout Board.
 */

/**@file
 *
 * @defgroup ble_sdk_app_bootloader_main main.c
 * @{
 * @ingroup dfu_bootloader_api
 * @brief Bootloader project main file.
 *
 * -# Receive start data packet. 
 * -# Based on start packet, prepare NVM area to store received data. 
 * -# Receive data packet. 
 * -# Validate data packet.
 * -# Write Data packet to NVM.
 * -# If not finished - Wait for next packet.
 * -# Receive stop data packet.
 * -# Activate Image, boot application.
 *
 */
#include "nrf_drv_config.h"
#include "dfu_transport.h"
#include "bootloader.h"
#include "bootloader_util.h"
#include <stdint.h>
#include <string.h>
#include <stddef.h>
#include "nordic_common.h"
#include "nrf.h"
#include "nrf_soc.h"
#include "app_error.h"
#include "nrf_gpio.h"
#include "ble.h"
#include "nrf.h"
#include "ble_hci.h"
#include "app_scheduler.h"
#include "app_timer_appsh.h"
#include "nrf_error.h"
#include "bsp.h"
#include "softdevice_handler_appsh.h"
#include "pstorage_platform.h"
#include "nrf_mbr.h"
#include "nrf_log.h"

#include "app_simple_timer.h"

#if BUTTONS_NUMBER < 1
#error "Not enough buttons on board"
#endif

#if LEDS_NUMBER < 1
#error "Not enough LEDs on board"
#endif

#define IS_SRVC_CHANGED_CHARACT_PRESENT 1                                                       /**< Include the service_changed characteristic. For DFU this should normally be the case. */

#define BOOTLOADER_BUTTON               BSP_BUTTON_0                                            /**< Button used to enter SW update mode. */
#define UPDATE_IN_PROGRESS_LED          BSP_LED_0                                               /**< Led used to indicate that DFU is active. */

#define APP_TIMER_PRESCALER             0                                                       /**< Value of the RTC1 PRESCALER register. */
#define APP_TIMER_OP_QUEUE_SIZE         4                                                       /**< Size of timer operation queues. */

#define SCHED_MAX_EVENT_DATA_SIZE       MAX(APP_TIMER_SCHED_EVT_SIZE, 0)                        /**< Maximum size of scheduler events. */

#define SCHED_QUEUE_SIZE                20                                                      /**< Maximum number of events in the scheduler queue. */


/**@brief Callback function for asserts in the SoftDevice.
 *
 * @details This function will be called in case of an assert in the SoftDevice.
 *
 * @warning This handler is an example only and does not fit a final product. You need to analyze 
 *          how your product is supposed to react in case of Assert.
 * @warning On assert from the SoftDevice, the system can only recover on reset.
 *
 * @param[in] line_num    Line number of the failing ASSERT call.
 * @param[in] file_name   File name of the failing ASSERT call.
 */
void assert_nrf_callback(uint16_t line_num, const uint8_t * p_file_name)
{
    app_error_handler(0xDEADBEEF, line_num, p_file_name);
}


/**@brief Function for initialization of LEDs.
 */
static void leds_init(void)
{
    nrf_gpio_range_cfg_output(LED_START, LED_STOP);
    nrf_gpio_pins_set(LEDS_MASK);
}


/**@brief Function for initializing the timer handler module (app_timer).
 */
static void timers_init(void)
{
    // Initialize timer module, making it use the scheduler.
    APP_TIMER_APPSH_INIT(APP_TIMER_PRESCALER, APP_TIMER_OP_QUEUE_SIZE, true);
}


/**@brief Function for initializing the button module.
 */
static void buttons_init(void)
{
    nrf_gpio_cfg_sense_input(BOOTLOADER_BUTTON,
                             NRF_GPIO_PIN_PULLUP, 
                             NRF_GPIO_PIN_SENSE_LOW);

}


/**@brief Function for dispatching a BLE stack event to all modules with a BLE stack event handler.
 *
 * @details This function is called from the scheduler in the main loop after a BLE stack
 *          event has been received.
 *
 * @param[in]   p_ble_evt   Bluetooth stack event.
 */
static void sys_evt_dispatch(uint32_t event)
{
    pstorage_sys_event_handler(event);
}


/**@brief Function for initializing the BLE stack.
 *
 * @details Initializes the SoftDevice and the BLE event interrupt.
 *
 * @param[in] init_softdevice  true if SoftDevice should be initialized. The SoftDevice must only 
 *                             be initialized if a chip reset has occured. Soft reset from 
 *                             application must not reinitialize the SoftDevice.
 */
static void ble_stack_init(bool init_softdevice)
{
    uint32_t         err_code;
    sd_mbr_command_t com = {SD_MBR_COMMAND_INIT_SD, };
    nrf_clock_lf_cfg_t clock_lf_cfg = NRF_CLOCK_LFCLKSRC;

    if (init_softdevice)
    {
        err_code = sd_mbr_command(&com);
        APP_ERROR_CHECK(err_code);
    }
    
    err_code = sd_softdevice_vector_table_base_set(BOOTLOADER_REGION_START);
    APP_ERROR_CHECK(err_code);
   
    SOFTDEVICE_HANDLER_APPSH_INIT(&clock_lf_cfg, true);

    // Enable BLE stack.
    ble_enable_params_t ble_enable_params;
    // Only one connection as a central is used when performing dfu.
    err_code = softdevice_enable_get_default_config(1, 1, &ble_enable_params);
    APP_ERROR_CHECK(err_code);

    ble_enable_params.gatts_enable_params.service_changed = IS_SRVC_CHANGED_CHARACT_PRESENT;
    err_code = softdevice_enable(&ble_enable_params);
    APP_ERROR_CHECK(err_code);
    
    err_code = softdevice_sys_evt_handler_set(sys_evt_dispatch);
    APP_ERROR_CHECK(err_code);
}


/**@brief Function for event scheduler initialization.
 */
static void scheduler_init(void)
{
    APP_SCHED_INIT(SCHED_MAX_EVENT_DATA_SIZE, SCHED_QUEUE_SIZE);
}

static int ledCounter = 0;
#define LED_COUNTER_TIMEOUT 1000 // 1ms

#define NUM_COUNTS 7
#define PAUSE_TIME 10000
const int countTops[NUM_COUNTS] = {10000, 5000, 3750, 2500, 1875, 1250, 1000};
const int countRepeats[NUM_COUNTS] = {1, 2, 3, 4, 5, 8, 10};
int countPosition = 0;
int repeatCounter = 0;
bool pauseBlink = 0;

void simple_timeout_handler(void * p_context)
{
	if (!pauseBlink)
	{
		if (++ledCounter >= countTops[countPosition])
		{
			ledCounter = 0;
			nrf_gpio_pin_toggle(UPDATE_IN_PROGRESS_LED);
			if (++repeatCounter >= countRepeats[countPosition])
			{
				repeatCounter = 0;
				countPosition += 1;
				if (countPosition >= NUM_COUNTS)
				{
					nrf_gpio_pin_clear(UPDATE_IN_PROGRESS_LED);
					pauseBlink = 1;
					countPosition = 0;
				}
			}
		}
	}
	else
	{
		if (++ledCounter >= PAUSE_TIME)
		{
			ledCounter = 0;
			pauseBlink = 0;
		}
	}
}

/**@brief Function for bootloader main entry.
 */
int main(void)
{
    uint32_t err_code;
    bool     dfu_start = false;
    bool     app_reset = (NRF_POWER->GPREGRET == BOOTLOADER_DFU_START);

    if (app_reset)
    {
        NRF_POWER->GPREGRET = 0;
    }
    
    leds_init();

    // This check ensures that the defined fields in the bootloader corresponds with actual
    // setting in the chip.
    APP_ERROR_CHECK_BOOL(*((uint32_t *)NRF_UICR_BOOT_START_ADDRESS) == BOOTLOADER_REGION_START);
    APP_ERROR_CHECK_BOOL(NRF_FICR->CODEPAGESIZE == CODE_PAGE_SIZE);

    // Initialize.
    timers_init();
    buttons_init();

    (void)bootloader_init();
	
    nrf_gpio_pin_clear(UPDATE_IN_PROGRESS_LED);
	
	//!
	app_simple_timer_init();
	app_simple_timer_start(APP_SIMPLE_TIMER_MODE_REPEATED, simple_timeout_handler, LED_COUNTER_TIMEOUT, NULL);
	//!
	
    if (bootloader_dfu_sd_in_progress())
    {
        //nrf_gpio_pin_set(UPDATE_IN_PROGRESS_LED);

        err_code = bootloader_dfu_sd_update_continue();
        APP_ERROR_CHECK(err_code);

        ble_stack_init(!app_reset);
        scheduler_init();

        err_code = bootloader_dfu_sd_update_finalize();
        APP_ERROR_CHECK(err_code);

        //nrf_gpio_pin_clear(UPDATE_IN_PROGRESS_LED);
    }
    else
    {
        // If stack is present then continue initialization of bootloader.
        ble_stack_init(!app_reset);
        scheduler_init();
    }

    dfu_start  = app_reset;
    dfu_start |= ((nrf_gpio_pin_read(BOOTLOADER_BUTTON) == 0) ? true: false);
    
    //if (dfu_start)nrf_gpio_pin_set(UPDATE_IN_PROGRESS_LED);
    
    if (dfu_start || (!bootloader_app_is_valid(DFU_BANK_0_REGION_START)))
    {
        //nrf_gpio_pin_set(UPDATE_IN_PROGRESS_LED);

        // Initiate an update of the firmware.
        err_code = bootloader_dfu_start();
        APP_ERROR_CHECK(err_code);
        //nrf_gpio_pin_clear(UPDATE_IN_PROGRESS_LED);
    }

    if (bootloader_app_is_valid(DFU_BANK_0_REGION_START) && !bootloader_dfu_sd_in_progress())
    {
        //nrf_gpio_pin_set(UPDATE_IN_PROGRESS_LED);
        // Select a bank region to use as application region.
        // @note: Only applications running from DFU_BANK_0_REGION_START is supported.
        bootloader_app_start(DFU_BANK_0_REGION_START);
    }
    
    //NVIC_SystemReset();
	//nrf_gpio_pin_set(UPDATE_IN_PROGRESS_LED);
}

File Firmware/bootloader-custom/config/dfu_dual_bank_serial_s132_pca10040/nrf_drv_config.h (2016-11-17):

/* Copyright (c) 2015 Nordic Semiconductor. All Rights Reserved.
 *
 * The information contained herein is property of Nordic Semiconductor ASA.
 * Terms and conditions of usage are described in detail in NORDIC
 * SEMICONDUCTOR STANDARD SOFTWARE LICENSE AGREEMENT.
 *
 * Licensees are granted free, non-transferable use of the information. NO
 * WARRANTY of ANY KIND is provided. This heading must NOT be removed from
 * the file.
 *
 */

#ifndef NRF_DRV_CONFIG_H
#define NRF_DRV_CONFIG_H

/**
 * Provide a non-zero value here in applications that need to use several
 * peripherals with the same ID that are sharing certain resources
 * (for example, SPI0 and TWI0). Obviously, such peripherals cannot be used
 * simultaneously. Therefore, this definition allows to initialize the driver
 * for another peripheral from a given group only after the previously used one
 * is uninitialized. Normally, this is not possible, because interrupt handlers
 * are implemented in individual drivers.
 * This functionality requires a more complicated interrupt handling and driver
 * initialization, hence it is not always desirable to use it.
 */
#define PERIPHERAL_RESOURCE_SHARING_ENABLED  0

/* CLOCK */
#define CLOCK_ENABLED 0

#if (CLOCK_ENABLED == 1)
#define CLOCK_CONFIG_XTAL_FREQ          NRF_CLOCK_XTALFREQ_Default
#define CLOCK_CONFIG_LF_SRC             NRF_CLOCK_LFCLK_Xtal
#define CLOCK_CONFIG_IRQ_PRIORITY       APP_IRQ_PRIORITY_LOW
#endif

/* GPIOTE */
#define GPIOTE_ENABLED 0

#if (GPIOTE_ENABLED == 1)
#define GPIOTE_CONFIG_USE_SWI_EGU false
#define GPIOTE_CONFIG_IRQ_PRIORITY APP_IRQ_PRIORITY_LOW
#define GPIOTE_CONFIG_NUM_OF_LOW_POWER_EVENTS 1
#endif

/* TIMER */
#define TIMER0_ENABLED 0

#if (TIMER0_ENABLED == 1)
#define TIMER0_CONFIG_FREQUENCY    NRF_TIMER_FREQ_16MHz
#define TIMER0_CONFIG_MODE         TIMER_MODE_MODE_Timer
#define TIMER0_CONFIG_BIT_WIDTH    TIMER_BITMODE_BITMODE_32Bit
#define TIMER0_CONFIG_IRQ_PRIORITY APP_IRQ_PRIORITY_LOW

#define TIMER0_INSTANCE_INDEX      0
#endif

#define TIMER1_ENABLED 1

#if (TIMER1_ENABLED == 1)
#define TIMER1_CONFIG_FREQUENCY    NRF_TIMER_FREQ_16MHz
#define TIMER1_CONFIG_MODE         TIMER_MODE_MODE_Timer
#define TIMER1_CONFIG_BIT_WIDTH    TIMER_BITMODE_BITMODE_16Bit
#define TIMER1_CONFIG_IRQ_PRIORITY APP_IRQ_PRIORITY_LOW

#define TIMER1_INSTANCE_INDEX      (TIMER0_ENABLED)
#endif
 
#define TIMER2_ENABLED 0

#if (TIMER2_ENABLED == 1)
#define TIMER2_CONFIG_FREQUENCY    NRF_TIMER_FREQ_16MHz
#define TIMER2_CONFIG_MODE         TIMER_MODE_MODE_Timer
#define TIMER2_CONFIG_BIT_WIDTH    TIMER_BITMODE_BITMODE_16Bit
#define TIMER2_CONFIG_IRQ_PRIORITY APP_IRQ_PRIORITY_LOW

#define TIMER2_INSTANCE_INDEX      (TIMER1_ENABLED+TIMER0_ENABLED)
#endif

#define TIMER3_ENABLED 0

#if (TIMER3_ENABLED == 1)
#define TIMER3_CONFIG_FREQUENCY    NRF_TIMER_FREQ_16MHz
#define TIMER3_CONFIG_MODE         TIMER_MODE_MODE_Timer
#define TIMER3_CONFIG_BIT_WIDTH    TIMER_BITMODE_BITMODE_16Bit
#define TIMER3_CONFIG_IRQ_PRIORITY APP_IRQ_PRIORITY_LOW

#define TIMER3_INSTANCE_INDEX      (TIMER2_ENABLED+TIMER1_ENABLED+TIMER0_ENABLED)
#endif

#define TIMER4_ENABLED 0

#if (TIMER4_ENABLED == 1)
#define TIMER4_CONFIG_FREQUENCY    NRF_TIMER_FREQ_16MHz
#define TIMER4_CONFIG_MODE         TIMER_MODE_MODE_Timer
#define TIMER4_CONFIG_BIT_WIDTH    TIMER_BITMODE_BITMODE_16Bit
#define TIMER4_CONFIG_IRQ_PRIORITY APP_IRQ_PRIORITY_LOW

#define TIMER4_INSTANCE_INDEX      (TIMER3_ENABLED+TIMER2_ENABLED+TIMER1_ENABLED+TIMER0_ENABLED)
#endif


#define TIMER_COUNT (TIMER0_ENABLED + TIMER1_ENABLED + TIMER2_ENABLED + TIMER3_ENABLED + TIMER4_ENABLED)

/* RTC */
#define RTC0_ENABLED 0

#if (RTC0_ENABLED == 1)
#define RTC0_CONFIG_FREQUENCY    32678
#define RTC0_CONFIG_IRQ_PRIORITY APP_IRQ_PRIORITY_LOW
#define RTC0_CONFIG_RELIABLE     false

#define RTC0_INSTANCE_INDEX      0
#endif

#define RTC1_ENABLED 0

#if (RTC1_ENABLED == 1)
#define RTC1_CONFIG_FREQUENCY    32768
#define RTC1_CONFIG_IRQ_PRIORITY APP_IRQ_PRIORITY_LOW
#define RTC1_CONFIG_RELIABLE     false

#define RTC1_INSTANCE_INDEX      (RTC0_ENABLED)
#endif

#define RTC2_ENABLED 0

#if (RTC2_ENABLED == 1)
#define RTC2_CONFIG_FREQUENCY    32768
#define RTC2_CONFIG_IRQ_PRIORITY APP_IRQ_PRIORITY_LOW
#define RTC2_CONFIG_RELIABLE     false

#define RTC2_INSTANCE_INDEX      (RTC0_ENABLED+RTC1_ENABLED)
#endif


#define RTC_COUNT                (RTC0_ENABLED+RTC1_ENABLED+RTC2_ENABLED)

#define NRF_MAXIMUM_LATENCY_US 2000

/* RNG */
#define RNG_ENABLED 0

#if (RNG_ENABLED == 1)
#define RNG_CONFIG_ERROR_CORRECTION true
#define RNG_CONFIG_POOL_SIZE        8
#define RNG_CONFIG_IRQ_PRIORITY     APP_IRQ_PRIORITY_LOW
#endif

/* PWM */

#define PWM0_ENABLED 0
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

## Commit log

2016-07-18 initial commit of hardware design
    [sparkfun-nrf52832-breakout.brd, sparkfun-nrf52832-breakout.sch]
2016-07-18 Schematic cleanup.
    [sparkfun-nrf52832-breakout.brd, sparkfun-nrf52832-breakout.sch]
2016-07-18 Adding cut-jumper to the power LED.
    [sparkfun-nrf52832-breakout.brd, sparkfun-nrf52832-breakout.sch]
2016-07-19 Updates after running checklist.
    [sparkfun-nrf52832-breakout.brd, sparkfun-nrf52832-breakout.sch]
2016-07-19 Adding test points to swd pins, stubs to NC QFN pins.
    [sparkfun-nrf52832-breakout.brd, sparkfun-nrf52832-breakout.sch]
2016-08-22 Moving test points to bottom, switching to micro fids, silk nudging.
    [sparkfun-nrf52832-breakout.brd, sparkfun-nrf52832-breakout.sch]
2016-08-23 Making SWD test points larger drill diameter.
    [sparkfun-nrf52832-breakout.brd, sparkfun-nrf52832-breakout.sch]
2016-08-24 Defaulting JP1 to closed.
    [sparkfun-nrf52832-breakout.brd, sparkfun-nrf52832-breakout.sch]
2016-08-24 Reducing nRF52832's center pad tcream to 33%.
    [sparkfun-nrf52832-breakout.brd, sparkfun-nrf52832-breakout.sch]
2016-08-24 Fixing version number on PCB.
    [sparkfun-nrf52832-breakout.brd]
2016-08-25 Adjusting silk.
    [sparkfun-nrf52832-breakout.brd]
2016-11-22 Adding of Values to SW1 and SW2
    3D Model Modification
    [sparkfun-nrf52832-breakout.brd, sparkfun-nrf52832-breakout.sch]

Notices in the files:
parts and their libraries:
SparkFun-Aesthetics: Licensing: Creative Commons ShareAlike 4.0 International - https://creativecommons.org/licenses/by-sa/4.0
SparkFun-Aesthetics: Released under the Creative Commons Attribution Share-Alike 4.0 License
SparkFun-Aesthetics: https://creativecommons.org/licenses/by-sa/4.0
